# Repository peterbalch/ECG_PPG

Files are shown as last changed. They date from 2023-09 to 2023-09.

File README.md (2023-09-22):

# ECG_PPG
3D-print files for PPG
3D-print files for ECG-PPG finger sensor clip in DesignSpark Mechanical format.
Also STL files.

The complete Instructable is at:

https://www.instructables.com/ECG-With-PPG-Using-Arduino/

I've included preliminary copies of the Instructable (as PDF) and the Arduino files here but they are not going to be updated. For the latest versions, see the Instructable.

If you have queries, please ask them on the Instructable web page. I will not monitor Github for comments.

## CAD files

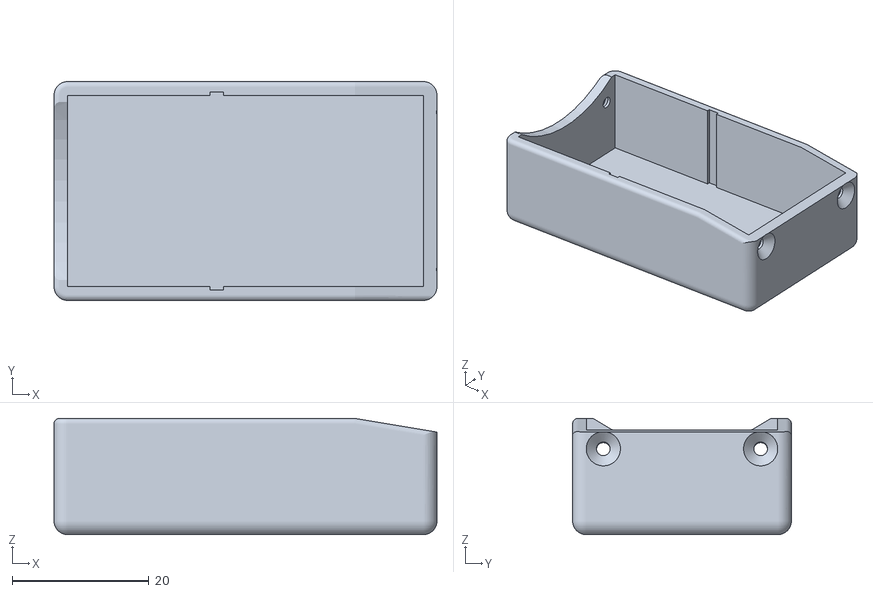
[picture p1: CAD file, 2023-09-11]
upper_box.stl
56.0 x 32.0 x 17.0

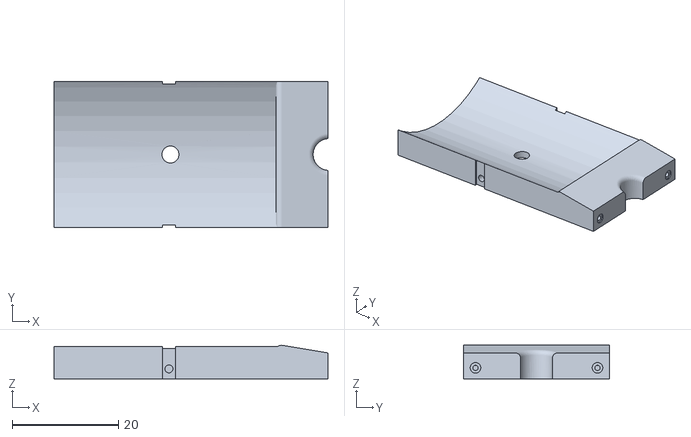
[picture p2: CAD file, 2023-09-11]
lower_slab.stl
51.7 x 27.6 x 6.32

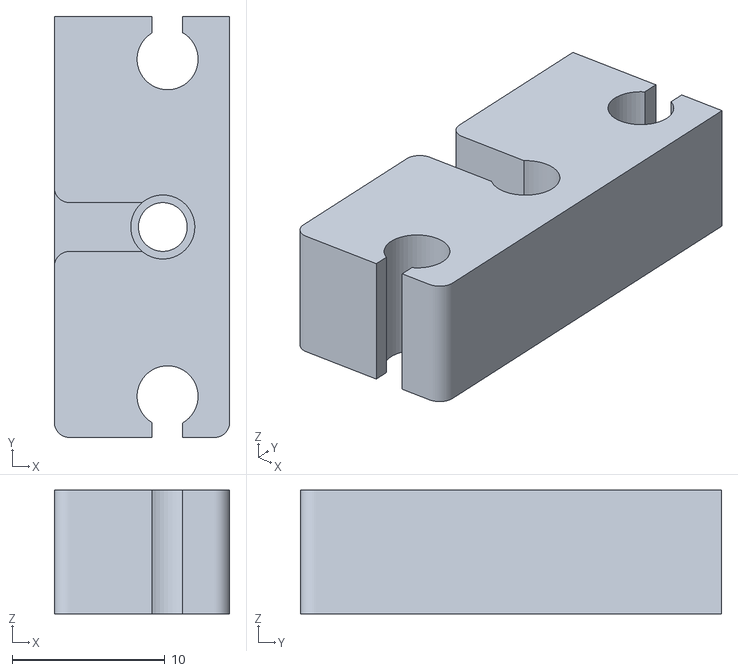
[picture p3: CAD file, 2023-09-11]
upper_led.stl
11.5 x 27.6 x 8.10

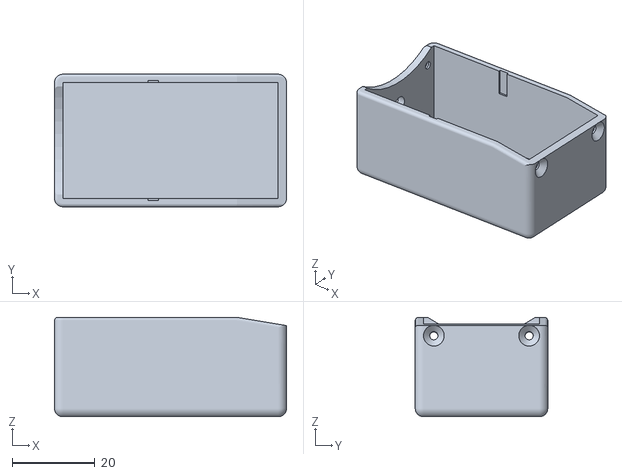
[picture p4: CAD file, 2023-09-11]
lower_box.stl
56.0 x 32.0 x 24.0

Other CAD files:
upper_slab.stl

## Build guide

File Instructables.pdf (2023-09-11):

### Introduction: ECG With PPG Using Arduino

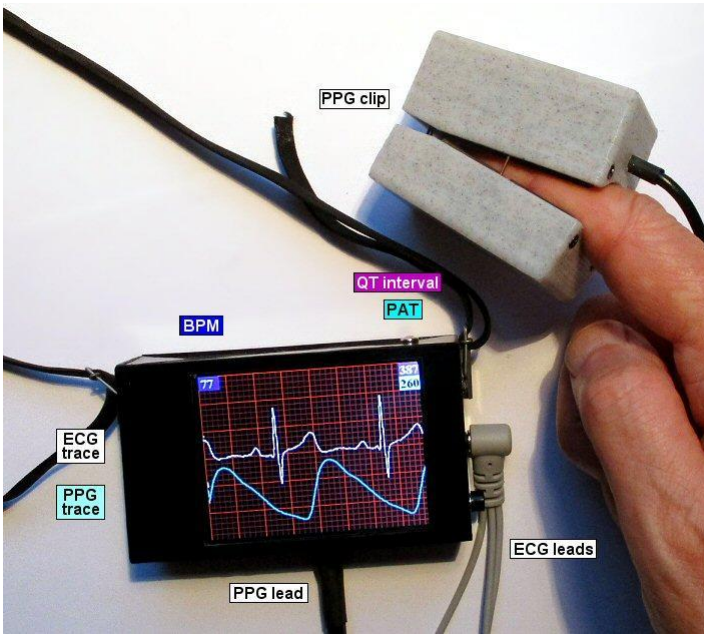
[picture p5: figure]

A plethysmogram is a graph of blood volume vs time and a photoplethysmogram (https://en.wikipedia.org/wiki/Photoplethysmogram) (PPG) uses light to measure blood volume, often with a finger probe.

You can buy a pulse oximeter very cheaply on eBay. It uses photoplethysmography to measure your heart-rate. By comparing the absorption of IR versus red light, it can also measure blood oxygen saturation. It's straightforward to build a PPG that measures red and IR absorption but calibrating it is a problem. The PPG described here only uses IR light.

This project is an add-on to my ECG project (https://www.instructables.com/ECG-Display-With-Arduino/) - I'm going to assume you've already built the ECG hardware. The additional hardware and software displays a photoplethysmogram next to the ECG trace. A probe clips on your finger and passes infra-red light through it. The amout of IR received is a measure of the blood volume in your finger.

There are two circuits you can use to collect the PPG data:

- build your own amplifier
- use an AD8232 module

Building your own amplifier is slightly cheaper and you probably already have all of the components. An AD8232 module is less work but you have to wait for it to be delivered.

I've included a design for a 3D printed PPG clip or you can use a piece of PVC plumbing pipe.

The new software includes code to calculate the QT-interval of the ECG signal. If you have built my ECG project, you can upgrade that project to display the QT-interval. (See the "Analysis" Step below.) You don't need to build PPG hardware.

This is not a medical device, it's something you're building for fun. See the full disclaimer in Step 2 of my ECG project. (https://www.instructables.com/ECG-Display-With-Arduino/)

### Step 1: What Is Photoplethysmography?

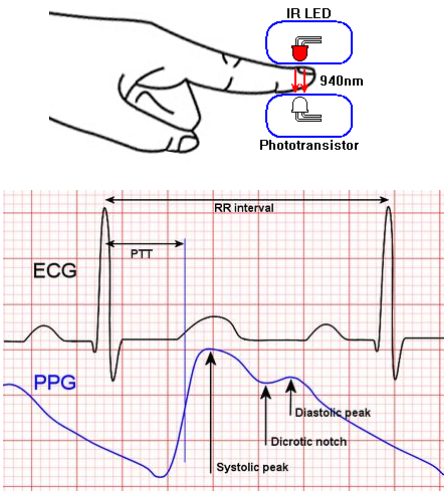
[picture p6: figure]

A PPG wave has a fast rise and a slow decline. During the decline there is a second peak. The first peak is the "systolic peak" and the second peak is the "diastolic peak". The dip between the two peaks is the "dicrotic notch".

The systolic peak is due to the pulse of blood arriving from the heart after systole (when the ventricles contract). The diastolic peak is due to reflection of that pulse from more peripheral parts of the blood system.

The size of the diastolic peak varies with where on the body you measure the PPG. It is quite large on the forehead and almost disappears at the toes.

The size of the diastolic peak also varies with age. It is quite large for young people and becomes smaller with age. The dicrotic notch is also large for young people and becomes smaller with age.

The heart rate can easily be measured using PPG and hence PPG can help detect arrythmia, tachycardia, atrial fibrillation, etc. But they can also be detected using the ECG trace.

The overall height of the PPG wave can be used to detect your breathing rate. There is decreased pulse amplitude and heart rate increases during inspiration. These effects are quite small and there are easier ways to detect respiration.

The time between the R wave of the ECG (the bigest peak) and the steepest part of the rise towards the systolic peak of the PPG is called the Pulse Arrival Time. (There are other slightly different definitions.)

The Pulse Transit Time is the time taken for the pulse to travel from, say, the shoulder to the finger or the face to the toe.

- PAT (pulse arrival time) - the time for the pulse to get from the heart to the

PPG probe

- PTT (pulse transit time) - the time for the pulse to get from, e.g., the

shoulder to the finger

But some people refer to both as Pulse Transit Time.

I'm going to refer to the time from the R-wave to the finger as PAT.

A typical PAT is in the range 200mS to 300mS.

Both Pulse Arrival Time (PAT) and Pulse Transit Time (PTT) can be used to estimate , arterial stiffness, artherosclerosis, arteriosclerosis, etc. But there is a lot of natural variation between individuals. The relationship between PAT and blood pressure has to be calibrated for each person. PAT may be useful to signal a sudden change in blood pressure, for instance, during a clinical procedure; it could signal the change faster than a cuff would.

The overall height of of the PPG is proportional to the pulse pressure. Pulse pressure is the difference between the systolic and diastolic pressure in the arteries. Higher pulse pressure may increase the risk heart attack or stroke. It may indicate atherosclerosis and stiffer arteries. Of course, the amplitude also depends on how far you've poked your finger into the PPG clip.

PPG is an active area of research. The bottom line is that it may be useful for diagnosis or it may not. The normal differences between individuals may be larger than the differences due to various health conditions. So it seems that you can use PPG to monitor changes in an andividual but not compare that individual to the general population.

There are many good reviews and discussions online, for instance here, (https://peterhcharlton.github.io/publication/ppg_sig_proc_chapter/) here (https://www.frontiersin.org/articles/10.3389/fphys.2021.808451/full) and here. (https://www.nature.com/articles/s41746-019-0136-7)

### Step 2: AD8232 Circuit

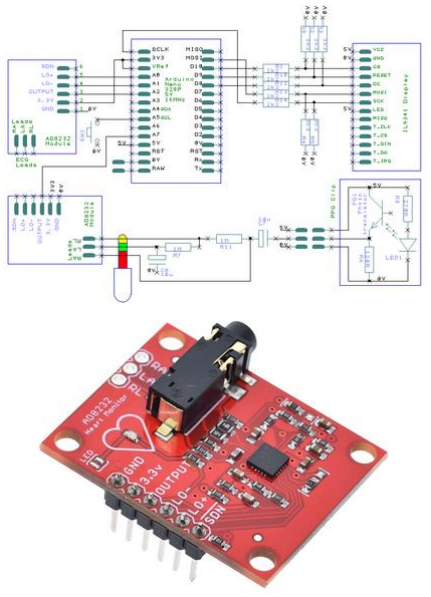
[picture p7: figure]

Skip to the next Step if you are building your own amplifier.

The AD8232 chip contains a high quality, low noise instrumentation amplifier and signal conditioning to remove noise. It is intended primarily for recording ECG but it works very well to record a PPG signal.

Buy a module like the one in the photo. Search eBay for "AD8232 module" or "ecg module". You don't need one with leads and electrode pads. You should already have a similar module measuring ECG.

R8 and LED1 produce infra-red light which passes through your finger to PD1. The current through PD1 produces a voltage across R1. That voltage is AC-coupled to the RA and LA inputs of the AD8232 module. The RA and LA inputs of the AD8232 module are connected to the RL (driven ground) output of the AD8232 through 1M resistors. That keeps the voltages at RL and RA in the correct range.

You can connect the PPG circuit to the AD8232 module using a 3.5mm jack plug or just solder the wires into the holes in the AD8232 PCB.

I suggest that you build the circuit on stripboard - it has very few components.

The value of R6 determines how large is the PPG signal. Try values between 100R and 470R.

The module produces mains hum when you connect the circuit to a computer with a USB lead. The hum goes away when the unit is disconnected.

### Step 3: Home-made Amplifier Circuit

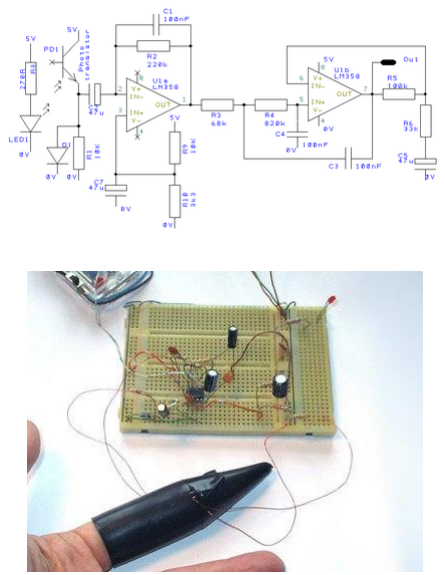
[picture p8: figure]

Skip to the next Step if you are using an AD8232 module.

The circuit consists of an IR LED emitter, an IR phototransistor receiver and an amplifier/filter based on an LM358 op-amp.

The current through the phototransistor produces a voltage across R1. That voltage is AC-coupled to the input of U1a (with a cutoff frequency of 3Hz). U1a has a V/V gain of 22x. C1 gives a slow roll-off above 7Hz. The circuit around U1b makes a low-pass Butterworth filter of around 10Hz with a V/V gain of 3x. Analog publish a good filter design tool here. (https://tools.analog.com/en/filterwizard/)

R1 is AC-coupled to U1a because if it is DC-coupled then changes in the overall light level shift the voltage across R1 and might drive the op-amp output to the power rail. If there is no finger in the clip then R1 goes to 5V

(or whatever the power level is). When you insert a finger, it takes up to 10sec for C1 to discharge to a reasonable input level for U1a. D1 stops R1 going above Vf of D1 (about 0.6V for a silicon diode). The circuit will work fine without D1 but it takes ages to get going. D1 can be any smallsignal silicon diode.

The IR LED is driven through a 270 ohm resistor giving a current of 15mA to 18mA. IR LEDs can often take up to 50mA but I wasn't wanting to drain the battery too quickly.

The output signal from U1b is around 1V high.

The IR emitter and receiver should have a wavelength in the range 900nm
- 940nm. Those wavelngths will pass through skin, muscle blood, etc. But they will be partially blocked if you have dark skin - that's because the job of melanin is to block light.

Choose an IR transmitter that matches the wavelength of the receiver. I chose

- IR LED = L-34F3C
- IR phototransistor = L-3DP3C

which peak at 940nm. Many other LEDs and phototransistors would work equally well - I happened to have lots of those ones. Search eBay or your favourite supplier for "IR LED" and "IR phototransistor" and choose ones that are 3mm dia. Make sure the wavelength is in the range 900nm -940nm.

The circuit is powered by a lithium cell (up to 4.2V) or from 4xAA cells (see Step 12 of my ECG project). So the "5V" in the schematic just means either 4V from the lithium cell or 5V from the Arduino.

If you were building this as a medical device, you'd use different filtering. You'd worry about the phase-shifts introduced by the filters - Chebyshev and Butterworth filters have different phase-shift. And you'd use a better quality op-amp!

### Step 4: Building the Circuit

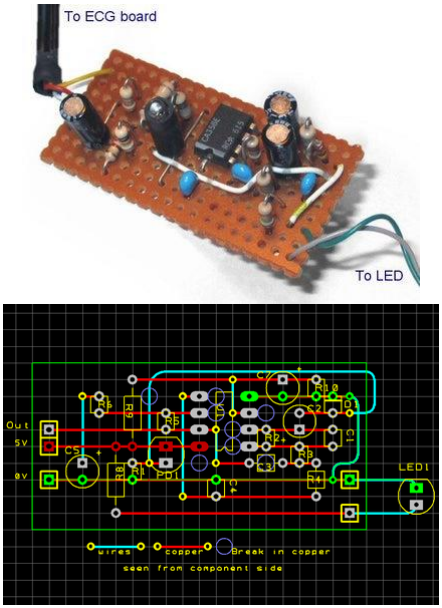
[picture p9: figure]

If you you have built your own amplifier:

I built the circuit on stripboard. It's a simple circuit and I'm far too impatient to wait for a commercial PCB. To keep the area small, I mounted most of the resistors vertically. The board is 1"x2" and is 15mm high. You can see the layout I used. If you prefer to use a "real" PCB then you can use SM parts to keep the height down.

The phototransistor is mounted in the centre of the board. The board is held in place in the clip with foam rubber arranged so the phototransistor pokes through a hole in the clip.

The LED is mounted in the other half of the clip on the end of wires. It is glued in place - I used UHU which is strong enough to work but can be pulled apart if you need to.

If you are using an AD8232 module:

The phototransistor, LED, R6 and R8 can be assembled inside the PPG clip. The R7, R11, C7 and C8 can be soldered onto a small piece of stripboard inside the case of your ECG.

### Step 5: Probe Clip

3 More Images

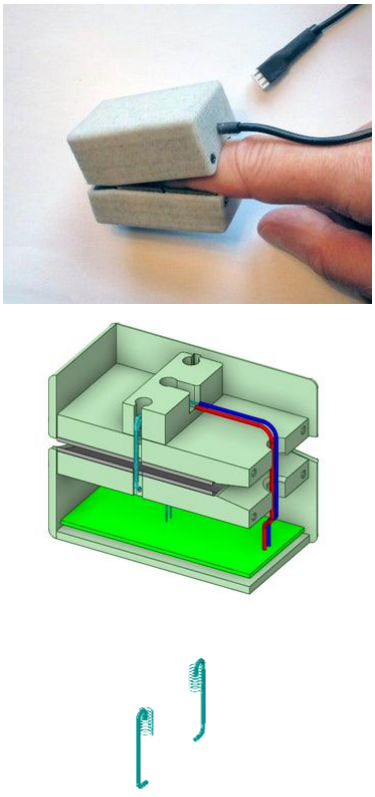
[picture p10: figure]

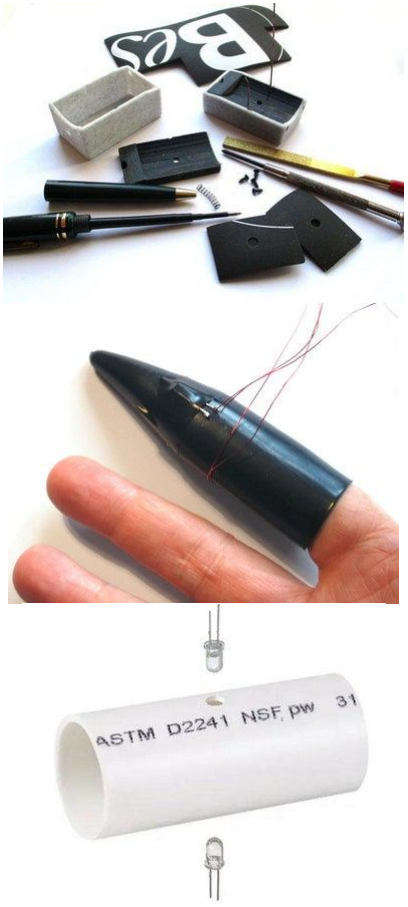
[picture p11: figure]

I used a 3D-printer to make the probe clip. The STL files are attached below.

As is usual with 3D-printing, you'll need to sand, file and drill the pieces so they fit. You'll need a 3.5mm (and maybe a 4mm) drill for the LED holes and maybe a 1.5mm drill for the screw-holes (depending on what screws you use).

The CAD model was designed using Designspark Mechanical. A free version can be downloaded (https://www.rs-online.com/designspark/mechanical-download-and-installation) from RS components. My Designspark source files are available here. (https://github.com/peterbalch/ECG_PPG)

I lined the clip with 1mm thick soft rubber from an old mouse-mat. It makes a better light-proof seal to your finger and is more comfortable. Bicycle inner-tube would also work.

The two halves of the clip are held together by bent wire and springs. I used a spring from a ballpoint pen that I cut in half. The wire is 0.5mm steel; a fine paperclip might work.

The clip is screwed together with 2x6mm self-tapping screws. Search eBay for "M2 countersunk self tapping screw". I find they're a useful size for assembling small 3D-printed items.

During development, I taped the LED and phototransistor into the walls of a black plastic tube. If you don't want to 3D-print a clip, you could make a more permanent version of that setup perhaps by using PVC plumbing tubing. "1/2 inch" pipe has an outside diameter of 21.4mm and an inside diameter of 18.0mm which should be OK unless you have particularly large fingers.

If you are using an AD8232 module: You don't need a big box on the PPG clip to house the amplifier - it's inside the case of the ECG. So print two copies of the smaller, "upper" box.

Attachments

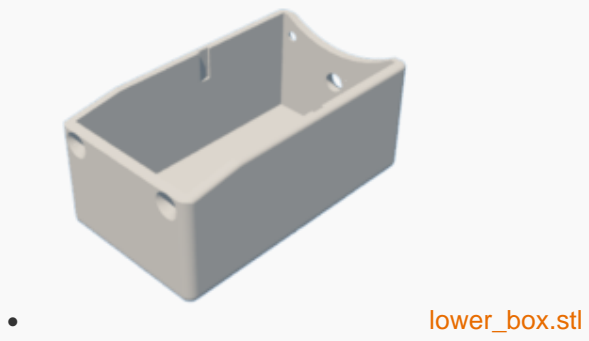
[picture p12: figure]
• lower_box.stl

Download (https://content.instructables.com/FBT/Z6LY/LMC1DFX6/FBTZ6LYLMC1DFX6.stl) | View in 3D

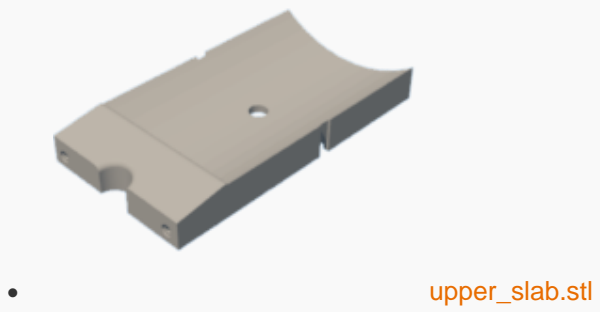
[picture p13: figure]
• upper_slab.stl

Download (https://content.instructables.com/FD6/OGLG/LMC1DFX5/FD6OGLGLMC1DFX5.stl) | View in 3D

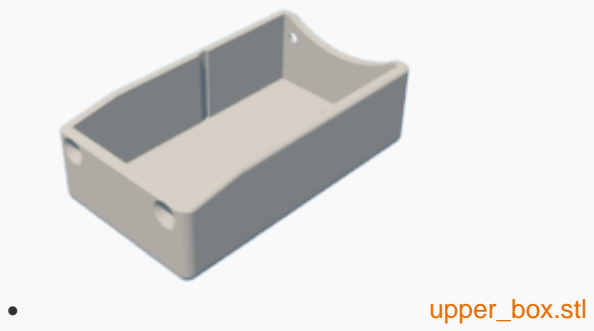
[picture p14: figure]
• upper_box.stl

Download (https://content.instructables.com/F60/IVPP/LMC1DFX8/F60IVPPLMC1DFX8.stl) | View in 3D

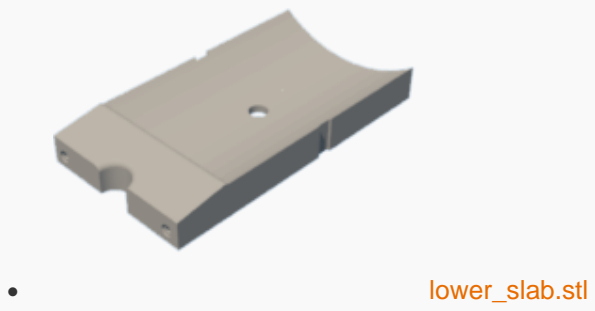
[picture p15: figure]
• lower_slab.stl

Download (https://content.instructables.com/FNC/DNY2/LMC1DFX7/FNCDNY2LMC1DFX7.stl) | View in 3D

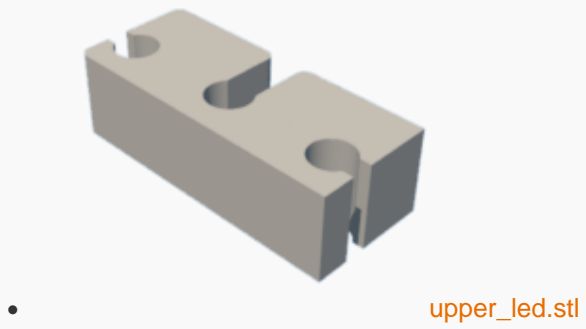
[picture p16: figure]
• upper_led.stl

Download (https://content.instructables.com/FQW/SJZ5/LMC1DFX9/FQWSJZ5LMC1DFX9.stl) | View in 3D

### Step 6: ECG Unit Hardware

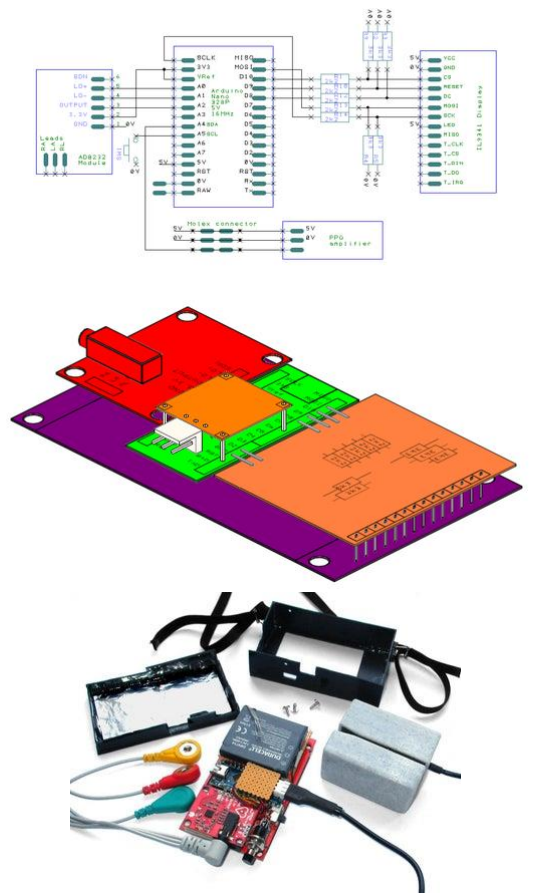
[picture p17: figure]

This plethysmogram is an add-on to my ECG project. The output from the PPG is connected to the A4 analogue input of the Arduino.

I decided to use a 3-pin 0.1" Molex connector. A stereo jack would look nicer but the AD8232 module of the ECG already uses a 3.5mm jack. It's important that the two connectors cannot be confused: you don't want to connect the 5V supply to the ECG electrodes attached to your body. A 2.5mm stereo jack would be better than a 0.1" Molex but I didn't have a 2.5mm plug/socket to hand.

If you you have built your own amplifier: The three wires connect to 0V, 5V and A4 of the Arduino Nano.

If you are using an AD8232 module: The phototransistor, LED, R6 and R8 can be assembled inside the PPG clip. The R7, R11, C7 and C8 can be soldered onto a small piece of strip-board inside the case of your ECG.

### Step 7: ECG Unit Software

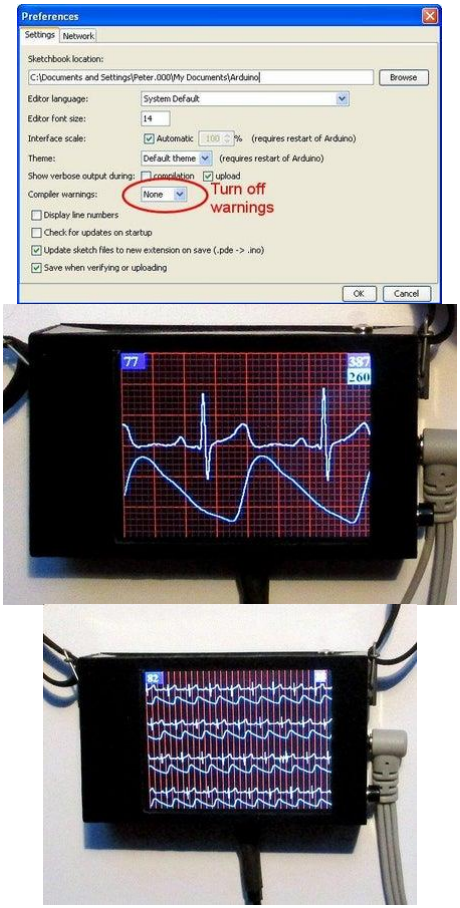
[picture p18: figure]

The PPG signal is shown when the ECG software is in the "Large display" or "Small display" mode. The PPG trace is drawn in cyan.

Download the files below. Copy the following files to a folder called ArduECGPPG:

- ArduECGPPG.ino
- SimpleILI9341.h
- SimpleILI9341.cpp

Turn off warnings. My code produces a lot of warnings which I find excessive and unhelpful. In the Arduino IDE (ver 1.8 or higher) select the File|Preferences menu item to open the Preferences dialog. Set Compiler Warnings to "None". Close the dialog.

To enable the PPG trace, ensure that bHasPPG is defined near the start of the sketch.

#define bHasPPG

If you comment it out then none of the PPG code will be executed.

Compile the files and upload them to the Nano.

If you you have built your own amplifier:

In ArduECGPPG.ino, A4 (the PPG signal) is defined as

pinMode(A4,INPUT_PULLUP)

So that if the PPG clip is disconnected then the input is pulled up to 5V. The sketch recognises that the the PPG signal is high and doesn't display it.

If you are using an AD8232 module:

With the AD8232 module, that "pullup" trick doesn't work - the AD8232 always produces an output in the right range. However, when the PPG clip is disconnected from the AD8232 module, the module produces a lot of noise. So as an additional test, the sketch looks at the total "energy" (the total changes across the sweep). If the "energy" is greater than a threshold then the next sweep of the screen is not displayed.

Attachments

- ArdECGPPG.ino

Download (https://content.instructables.com/F5Y/FW8Y/LMC1DK34/F5YFW8YLMC1DK34.ino)

- SimpleILI9341.cpp

Download (https://content.instructables.com/FPA/8KQ7/LMC1DK35/FPA8KQ7LMC1DK35.cpp)

- SimpleILI9341.h

Download (https://content.instructables.com/F6H/KKB0/LMC1DK36/F6HKKB0LMC1DK36.h)

### Step 8: Analysis

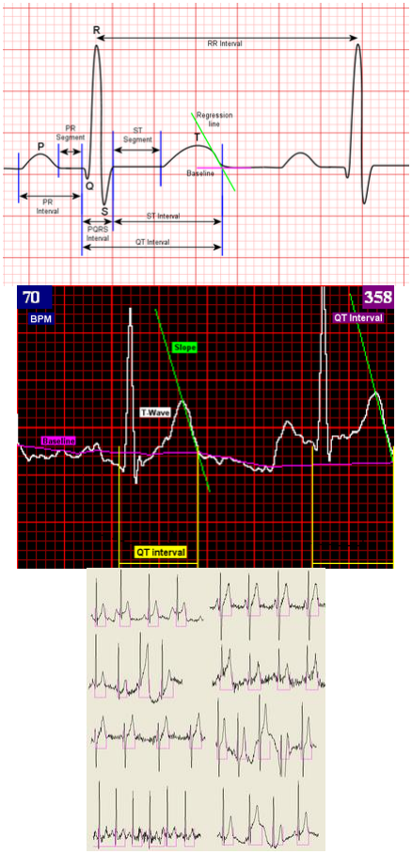
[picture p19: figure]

The interval between the ECG and the PAT is displayed.

PAT is measured from the peak of the ECG R-wave to somewhere in the systolic peak. Some researchers measure to the top of the systolic peak and some measure to the biggest upward slope of the systolic peak (which is what this sketch does).

The sketch has a new feature: it can estimate the QT interval. To enable QT estimation ensure that bHasQT is defined near the start of the sketch.

#define bHasQT

QT interval is a useful measurement in predicting ventricular arrhythmias. "Long QT syndrome" can be congenital or due to various medications.

It is hard to automate the calculation and many doctors don't trust automated systems. There are lots of different attempts at algorithms which implies to me that the problem has not been "solved". The result you get can depend on where you've placed the leads.

The QT interval is defined to be the time from the start of the Q-wave to the end of the T-wave. (https://en.wikipedia.org/wiki/T_wave) The start of the Q-wave is the time at which the ECG signal starts to dip just before the large R spike. The end of the T-wave is where a line drawn through the falling part of the T-wave meets the baseline. In textbooks, it looks easy.

In the real world it's much harder. There is noise in the signal. Where is the "baseline"? What is the slope of the T-wave? Where do you measure it?

The rest of this Step describes my solution. You can skip it unless you're interested in the maths.

The start of the Q-wave is easy. It's the sample after the last time the differential of the signal was positive before the R spike. You have to smooth the signal to remove the worst noise. I say that the Q-wave is easy because the Q-wave is so quick that any mistake you make will only affect the estimated QT-interval by a few milliSeconds.

The T-wave is harder because it's slower and more vague. The algorithm I've developed for finding the end of the T-wave is as follows.

The ECG signal is differentiated and smoothed. The peak of the R-wave corresponds with the biggest value of the differentiated ECG signal.

The peak of the T-wave is located. It is the highest value of the ECG signal that is between 200mS and 500mS after the R-wave.

Once the peak of the T-wave is found, the program calculates the regression line of the signal from the peak to 100mS after the peak. The program starts collecting:

- the sum of a
- the sum of T
- the sum of T*a
- the sum of T*T

(where 'T' is the time since the R-peak and 'a' is the ECG signal)

The summing stops 100mS after the R-peak and the line is calculated. However the values are weighted so that values half through the 100mS interval are worth more.

The values that have been summed allow us to calculate the regression line. (https://en.wikipedia.org/wiki/Linear_regression)

You will have been taught the formula for regression in any statistics course:

a = (Σxy - Σx*Σy/n)/(Σx²-Σx*Σx/n);
b = (Σy-a*Σx)/n;
(where y = ax + b}

The end of the T-wave is where the line crosses the "baseline" but where is the baseline?

The ECG signal is exponentially smoothed. (https://en.wikipedia.org/wiki/Exponential_smoothing) When each sample arrives, it is smoothed using

smoothed_sample = smoothed_sample*alpha + sample*(1-alpha); Alpha ought to be calulated as

alpha = exp(-1/Tau);
but it can be approximated more cheaply as

alpha = 1 - 1/Tau;
The bigger Tau (the time-constant) the more the signal is smoothed; i.e. the more slowly the smoothed signal changes.

The estimated baseline is an exponentially smoothed copy of the signal. The time-constant of the exponential is longer when the signal is further from the current estimated baseline:

- "sample" is latest sample
- diff is (first derivative of sample)²
- ds is diff smoothed with time_const=20mS
- Tau = 2*(ds+sqr(sample-baseline)+1)

The baseline is "sample" (the latest sample) smoothed using a time-constant of Tau. So the baseline changes slowly due to big sudden changes (like the R-wave and T-wave) but stays close to (what a human thinks is) the true baseline.

The "first derivative of sample" is, in fact, sample[i]-sample[i-n]. Where n is chosen to be around 20mS before. (The larger the value of "n", the more the differential is smoothed.)

I admit, a lot of the algorithm is rather arbitrary but it works at least as well as other algorithms you can find in scientific papers. The images above show the results when applied to a database (https://physionet.org/content/ecgiddb/1.0.0/) of typical "real world" recordings that contain all sorts of errors.

The normal QT interval is in the range:

- Men 390 - 450ms
- Women 390 - 460ms

but it depends on the heart-rate. The QT interval is therefore adjusted to compensate for heart-rate to give QTc.

Several compensation formulae are used:

- Bazett formula: QTc = QT/sqrt(RR/1000)
- Fridericia formula: QTc = QT/((RR/1000)^(1/3))
- Framingham formula: QTc = QT + 0.154 * (1 - RR)
- Hodges formula: QTc = QT + 0.154*(1000-RR)

(QT and RR are in mS.)

Graphs of those formulae are shown above: a QT interval of 400mS is "compensated" for various heart-rates.

I have chosen the Fridericia formula which is widely used. In fact, I've recalculated the Fridericia formula as a quadratic equation so as not to have to calculate a cube root (which is very slow on a Nano). I'll call it "Peter's formula":

- Peter's formula: QTc = QT * ((0.00728 - 0.0000164*BPM)*BPM + 0.622)

It gives the same answer as the Fridericia formula to within about 1mS over the normal range QT interval and heart-rate (BPM).

The QTc value that the program displays is the calculated QTc filtered through an order-5 median filter and a low-pass filter. A median filter is useful when noise give rise to a couple of really weird values. The low-pass filter stops the displayed values changing too quickly.

### Step 9: The Future

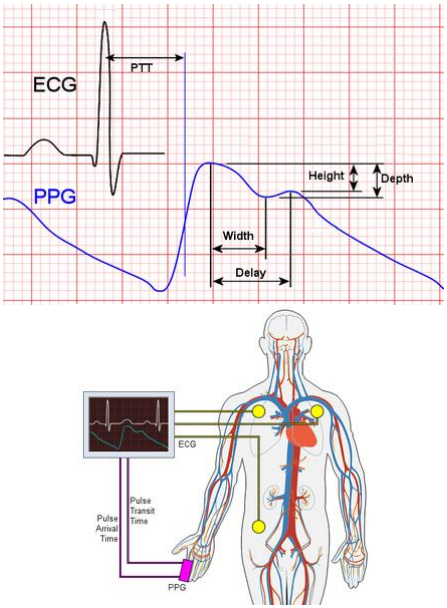
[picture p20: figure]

How can this project be taken forward?

You could save power by only turning on LED when measuring - but then the amplifier must respond quickly and filtering must be done in s/w. You could measure the light level twice with the LED off then on and use the difference to compensate for ambient light levels.

You could automate further analysis of the PPG signal. Researchers have tried to automate the measurement of various aspects of the PPG signal:

- the pulse arrival time (PAT)
- the rise time of the systolic pulse

- the fall time of the diastolic pulse
- the relative heights of the systolic and diastolic peaks
- the time from systolic peak to diastolic peak
- the amplitude of the systolic peak
- the depth of the dicrotic notch
- the areas of different parts of the curve

Researchers attempt to correlate different measurements with blood pressure, stroke volume, arterial stiffness, atherosclerosis, pain level, breathing rate, etc. They look at the first, second and third derivative of the PPG and even use Fourier transforms and wavelet analysis. By comparing PAT for proximal and distal PPGs, the state of different arteries can be estimated.

The problem is that differences between individuals are large. It can depend on skin type, ambient light, limb length, body temperature, etc. You need to calibrate each individual so it is only useful statistically with large populations or to asses the ongoing response of an individual to treatment.

You could add a second PPG probe and measure both pulse arrival time and pulse transit time. This group (https://ieeexplore.ieee.org/abstract/document/9646921) use a clip as long as the finger with a PPG sensor at each end to measure pulse wave velocity. They claim that it's 90% accurate for systolic blood pressure and 63% accurate for diastolic blood pressure.

The current sketch measures the heart-rate and draws the Poincare display by looking at the ECG. You could dispense with the ECG altogether and display only the PPG and a Poincare display.

It would be nice to save a whole day's worth of data. That's about 68Mbytes of data (assuming one-byte values). The write time of an SD card is very variable so I would probably use two Arduinos: one to collect the samples and one to buffer them and write to the SD card.

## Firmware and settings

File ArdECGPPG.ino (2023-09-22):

//-----------------------------------------------------------------------------
// Copyright 2023 Peter Balch
//   displays an ECG and PPG
//   computes QT interval
//   computes PAT
//-----------------------------------------------------------------------------

#include <Arduino.h>
#include <SPI.h>
#include "SimpleILI9341.h"

//-----------------------------------------------------------------------------
// Defines
//-----------------------------------------------------------------------------

#define bHasPPG
#define bHasPAT
#define bHasQT
#define bHasChartMode

#ifdef bHasPAT
#define bHasPPG
#endif

//#define bDebug
//#define bWindows
//#define bFakeECGoutput
//#define bFakeInput

// get register bit - faster: doesn't turn it into 0/1
#ifndef getBit
#define getBit(sfr, bit) (_SFR_BYTE(sfr) & _BV(bit))
#endif
#define sqr(x) ((x)*(x))

//-----------------------------------------------------------------------------
// Global Constants and Typedefs
//-----------------------------------------------------------------------------

const int TFT_WIDTH = 320;
const int TFT_HEIGHT = 240;

// pins
const int ECG_IN = A2;
#ifdef bHasPPG
const int PPG_IN = A4;
int16_t ppgmin = 1024;
static uint32_t ppgEnergy = 0;
#endif

#ifdef bFakeECGoutput
const int FAKE_OUT = 3;
#endif

const int BUTTON_IN = A5;
const int LO_P_IN = A0;
const int LO_N_IN = A1;

// Display pins
const int TFT_CS    = 10;
const int TFT_CD    = 8;
const int TFT_RST   = 9;

const int sps = 200; // Samples per Sec
const int SamplePeriod = 1000 / sps; // mSec
const int PoincareScale = 10;
const int PoincareLeft = 40;
const int PoincareBottom = TFT_HEIGHT - 12;
const int nDiff = sps / 65; /* differentiate = aa[i]-aa[i-nDiff]*/

//-----------------------------------------------------------------------------
// Global Variables
//-----------------------------------------------------------------------------

uint16_t DisplayRepeat = TFT_WIDTH; // helps keep the R peak centred
uint8_t ignoreBeats = 0; // blank the screen after an error
int16_t lastNegDiff1, lastNegDiff2; // how long ago was the last time the differential was negative
uint16_t CurBPM = 60;
#ifdef bHasPPG
  uint8_t PPGreceived = 0; // count how many PPG signals (value < 1000) have been received to check that the PPG is plugged in
  const uint8_t PPGreceivedMin = 100; // must have received >= 100 valid values
#endif
#ifdef bHasQT
  uint16_t CurQT = 360;
#endif
#ifdef bHasPAT
  float CurPAT = 0;
#endif

enum TMode { mdLargeECG, mdSmallECG,  mdPoincare, mdBattery } mode = mdLargeECG;

bool SendingSerial = false;

//---------------------------------------------------------------------------

#ifdef bFakeInput
#include "FakeInput.h"
#endif

//---------------------------------------------------------------------------
// TimeConst
//   calc Alpha for a time constant of a decay
//    n: number of samples for exponential smoothing
//    returns exp(-1 / n);
//---------------------------------------------------------------------------
float TimeConst(float n) {
  return exp(-1 / n);
}

//---------------------------------------------------------------------------
// MedianOfThree
//    c,d,e: three values
//    returns median value
//---------------------------------------------------------------------------
int16_t MedianOfThree(int16_t c, int16_t d, int16_t e) {
  int16_t tmp;
  if (d < c) {    tmp = c;    c = d;    d = tmp;  };
  if (e < c) {    e = c;  };
  if (d < e) return d; else return e;
}

//---------------------------------------------------------------------------
// MedianOfFive
//    a,b,c,d,e: five values
//    returns median value
//---------------------------------------------------------------------------
int16_t MedianOfFive(int16_t a, int16_t b, int16_t c, int16_t d, int16_t e) {
  int16_t tmp;
  if (b < a) {    tmp = a;    a = b;    b = tmp;  }
  if (d < c) {    tmp = c;    c = d;    d = tmp;  }
  if (c < a) {    tmp = b;    b = d;    d = tmp;    c = a;  }
  if (b < e) {    tmp = e;    e = b;    b = tmp;  }
  if (e < c) {    tmp = b;    d = tmp;  e = c;    }
  if (d < e) return d; else return e;
}

//-----------------------------------------------------------------------------
// DrawGridSmall
//   draw empty grid for small display
//-----------------------------------------------------------------------------
void DrawGridSmall(void)
{
  int16_t  i;
  ClearDisplay(TFT_BLACK);

  #ifdef bHasChartMode
    for (i=0; i < TFT_WIDTH; i++)
      if (i*4*5 % sps == 0)
        DrawVLine(i, 0, TFT_HEIGHT/4, TFT_RED);
    for (i=TFT_HEIGHT/4; i < TFT_HEIGHT; i+=TFT_HEIGHT/16)
      if (i % (TFT_HEIGHT/4) == 0)
        DrawHLine(0, i, TFT_WIDTH, TFT_DARKGRAY); else
        DrawHLine(0, i, TFT_WIDTH, TFT_MAROON);
  #else
    for (i = 0; i < TFT_WIDTH; i++)
      if (i*4*5 % sps == 0)
        DrawVLine(i, 0, TFT_HEIGHT, TFT_RED);
  #endif
}

//-----------------------------------------------------------------------------
// DrawPoincareLine
//   draw a Line on the Poincare display
//    x1,y1: start point
//    x2,y2: end point
//    color: the color it is to be drawn
//-----------------------------------------------------------------------------
void DrawPoincareLine(int16_t x1, int16_t y1, int16_t x2, int16_t y2, uint16_t color)
{
  DrawLine(
    constrain(PoincareLeft + x1 / PoincareScale, 0, TFT_WIDTH - 1),
    constrain(PoincareBottom - y1 / PoincareScale, 0, TFT_HEIGHT - 1),
    constrain(PoincareLeft + x2 / PoincareScale, 0, TFT_WIDTH - 1),
    constrain(PoincareBottom - y2 / PoincareScale, 0, TFT_HEIGHT - 1),
    color);
}

//-----------------------------------------------------------------------------
// DrawPoincareFrame
//   draw a rectangle Poincare display 
//    x1,y1,x2,y2: the corners of the frame
//    color: the color it is to be drawn
//-----------------------------------------------------------------------------
void DrawPoincareFrame(int16_t x1, int16_t y1, int16_t x2, int16_t y2, uint16_t color)
{
  DrawPoincareLine(x1, y1, x2, y1, color);
  DrawPoincareLine(x2, y1, x2, y2, color);
  DrawPoincareLine(x2, y2, x1, y2, color);
  DrawPoincareLine(x1, y2, x1, y1, color);
}

//-----------------------------------------------------------------------------
// DrawGridPoincare
//   draw Poincare display background
//-----------------------------------------------------------------------------
void DrawGridPoincare(void)
{
#define TFT_DARKDARKGRAY    RGB(64,64,64)
  const uint8_t f[4] = { 30, 60, 100, 160 };
  int16_t i, b;

  ClearDisplay(TFT_BLACK);

  for (i = 0; i < sizeof(f); i++) {
    b = 60000 / f[i] / PoincareScale;
    DrawVLine(PoincareLeft + b, 0, PoincareBottom, TFT_DARKDARKGRAY);
    DrawHLine(PoincareLeft, PoincareBottom - b, TFT_WIDTH, TFT_DARKDARKGRAY);
    ILI9341SetCursor(PoincareLeft + b - 8, TFT_HEIGHT);
    DrawInt(f[i], MediumFont, TFT_WHITE);
    ILI9341SetCursor(PoincareLeft - 20, PoincareBottom - b + 4);
    DrawInt(f[i], MediumFont, TFT_WHITE);
  }
  DrawLine(PoincareLeft, PoincareBottom, PoincareLeft + PoincareBottom, 0, TFT_DARKDARKGRAY);

  DrawPoincareLine(500, 500, 1115, 916, TFT_DARKGREEN); // normal
  DrawPoincareLine(1115, 916, 1115, 1115, TFT_DARKGREEN);
  DrawPoincareLine(1115, 1115, 916, 1115, TFT_DARKGREEN);
  DrawPoincareLine(916, 1115, 500, 500, TFT_DARKGREEN);
  DrawPoincareFrame(500, 1200, 700, 2500, TFT_MAROON); // N-V-N
  DrawPoincareFrame(1200, 500, 2500, 700, TFT_MAROON);
  DrawPoincareFrame(500, 500, 700, 1200, RGB(48, 48, 0)); // premature ventricular
  DrawPoincareFrame(500, 500, 1200, 700, RGB(48, 48, 0));
  DrawPoincareLine(320, 320, 320, 650, RGB(0, 0, 64)); // atrial fibrilation
  DrawPoincareLine(320, 650, 800, 1700, RGB(0, 0, 64));
  DrawPoincareLine(800, 1700, 1700, 1700, RGB(0, 0, 64));
  DrawPoincareLine(1700, 1700, 1700, 800, RGB(0, 0, 64));
  DrawPoincareLine(650, 320, 1700, 800, RGB(0, 0, 64));
  DrawPoincareLine(650, 320, 320, 320, RGB(0, 0, 64));
  DrawPoincareFrame(1700, 900, 2500, 1400, RGB(0, 32, 32)); // missed beat
  DrawPoincareFrame(900, 1700, 1400, 2500, RGB(0, 32, 32));

  DrawVLine(PoincareLeft, 0, PoincareBottom, TFT_WHITE);
  DrawHLine(PoincareLeft, PoincareBottom, TFT_WIDTH, TFT_WHITE);
}

//-----------------------------------------------------------------------------
// DrawGridVLine
//   for Large display, draw a part of the grid
//    x: column
//    y1,y2: ends of line
//-----------------------------------------------------------------------------
void DrawGridVLine(int16_t x, int16_t y1, int16_t y2)
{
  int16_t y;

  if (y1 > y2)
    DrawGridVLine(x, y2, y1); else
  {
    if (x * 5 % (1000 / SamplePeriod) == 0)
      DrawVLine(x, y1, y2 - y1 + 1, TFT_RED); else if (x * 25 % (1000 / SamplePeriod) == 0)
      DrawVLine(x, y1, y2 - y1 + 1, TFT_MAROON); else
    {
      DrawVLine(x, y1, y2 - y1 + 1, TFT_BLACK);
      for (y = y1; y <= y2; y++)
        if (y % 40 == 0)
            DrawPixel(x, y, TFT_RED); else if (y % 8 == 0)
          DrawPixel(x, y, TFT_MAROON);
    }
  }
}

//-----------------------------------------------------------------------------
// DrawPoincare
//   draw the current BPM in the Poincare display 
//    Poincare plot
//    init: initialise the points array?
//-----------------------------------------------------------------------------
void DrawPoincare(bool init)
{
  const int nPeriods = 400;
  static uint8_t Periods[nPeriods] = {0};
  static int16_t i = 0;
  int16_t prev,t;

  if (init) {
    memset(Periods, 0, sizeof(Periods));
    return;
  }

  t = 60000 / (CurBPM*PoincareScale);

  prev = Periods[i];
  i = (i + 1) % nPeriods;
  if (PoincareLeft + Periods[i] > 0)
    DrawPixel(PoincareLeft + Periods[i], PoincareBottom - (Periods[(i + 1) % nPeriods]), TFT_BLACK);
  Periods[i] = t;
  if (prev > 0)
    DrawPixel(PoincareLeft + prev, PoincareBottom - t, TFT_WHITE);
}

//-----------------------------------------------------------------------------
// DrawGridLarge
//   draw the background of the Large display 
//-----------------------------------------------------------------------------
void DrawGridLarge(void)
{
  int16_t i;
  ClearDisplay(TFT_BLACK);
  for (i = 0; i < TFT_HEIGHT; i++)
    if (i % 8 == 0)
      DrawHLine(0, i, TFT_WIDTH, TFT_MAROON);
  for (i = 0; i < TFT_WIDTH; i++)
    if (i * 25 % (1000 / SamplePeriod) == 0)
      DrawVLine(i, 0, TFT_HEIGHT, TFT_MAROON);

  for (i = 0; i < TFT_HEIGHT; i++)
    if (i % 40 == 0)
      DrawHLine(0, i, TFT_WIDTH, TFT_RED);
  for (i = 0; i < TFT_WIDTH; i++)
    if (i * 5 % (1000 / SamplePeriod) == 0)
      DrawVLine(i, 0, TFT_HEIGHT, TFT_RED);
}

//-----------------------------------------------------------------------------
// DrawGrid
//   draw the background of the current display 
//-----------------------------------------------------------------------------
void DrawGrid(void)
{
  switch (mode) {
    case mdLargeECG: DrawGridLarge(); break;
    case mdSmallECG: DrawGridSmall(); break;
    case mdPoincare: DrawGridPoincare(); break;
    case mdBattery: ClearDisplay(TFT_BLACK); break;
  }
  DisplayRepeat = TFT_WIDTH;
  DrawPoincare(true);
  ignoreBeats = 2;
}

//-----------------------------------------------------------------------------
// centrePeak
//   attempt to keep a peak in the first third of the screen
//    x: position of the peak being drawn
//-----------------------------------------------------------------------------
void centrePeak(uint16_t x)
{
  uint16_t period = (60000L/SamplePeriod) /CurBPM;
  int16_t b;
  static int16_t dr = 480;
  static int16_t dt = 0;

  b = period;
  while (b < TFT_WIDTH)
    b += period;
  if (b > dr+10)
    dr += 10; else
  if (b < dr-10)
    dr -= 10;
  if (b > dr)
    dr++; else
    dr--;
  dr = constrain(dr,TFT_WIDTH-1,2*TFT_WIDTH);
  DisplayRepeat = dr;
  if (x < 80)
    dt--; else
  if (x < 160)
    dt++;
  DisplayRepeat += dt;
  DisplayRepeat = constrain(DisplayRepeat,TFT_WIDTH-1,2*TFT_WIDTH);
}

//-----------------------------------------------------------------------------
// DrawBattVolts
//-----------------------------------------------------------------------------
void DrawBattVolts(void)
{
  const int xBatt = 50;
  const int yBatt = 100;
  static int maxBatt = 3300;
  static unsigned long nextTime = 0;
  int v = read3V3();
  const int w = 40;

  maxBatt = max(maxBatt, v);

  if (millis() > nextTime) {
    nextTime = millis() + 1000;
    ILI9341SetCursor(xBatt, yBatt + 15);
    DrawStringF(F("Battery "), LargeFont, TFT_WHITE);
    DrawBox(Cursorx, yBatt, 54, 20, TFT_BLACK);
    DrawInt(maxBatt, LargeFont, TFT_WHITE);
    maxBatt = 0;

    DrawBox(0, 0, 50, 20, TFT_NAVY);
    ILI9341SetCursor(4, 16);
    DrawStringF(F("BPM"), LargeFont, TFT_WHITE);
    #ifdef bHasQT
      DrawBox(TFT_WIDTH - w, 0, w, 20, TFT_PURPLE);
      ILI9341SetCursor(TFT_WIDTH - w + 2, 16);
      DrawStringF(F("QT"), LargeFont, TFT_WHITE);
    #endif
    #ifdef bHasPAT
      if (PPGreceived >= PPGreceivedMin) {
        #ifdef bHasQT
          const int y = 20;
        #else
          const int y = 0;
        #endif
        DrawBox(TFT_WIDTH - w, y, w, 20, TFT_CYAN);
        ILI9341SetCursor(TFT_WIDTH - w + 1, y + 16);
        DrawStringF(F("PAT"), LargeFont, TFT_BLACK);
      }  
    #endif
  }
}

//-----------------------------------------------------------------------------
// DrawChart
//   draw the current BPM and PAY in the vhart display 
//    init: initialise the display?
//-----------------------------------------------------------------------------
#ifdef bHasChartMode
void DrawChart(bool init)
{
  static int16_t x = -1;
  static uint8_t pyBPM = 0;
  static uint8_t pyPAT = 0;
  static uint8_t yofs = TFT_HEIGHT/4;
  int16_t y4, y;
  const int16_t  minBPM = 40;
  const int16_t  maxBPM = 150;
  const int16_t  minPAT = 150;
  const int16_t  maxPAT = 400;
  const int16_t  BPMmaxRed = 120; // BPM above this shown as red
  const int16_t  BPMmaxYellow = 100; // BPM above this shown as Yellow
  const int16_t  BPMminYellow = 50; // BPM below this shown as Yellow
  const int16_t  BPMminRed = 40; // BPM below this shown as red

  if (init) {
    x = -1;
    yofs = 0;
    return;
  }

  x++;
  x = x % TFT_WIDTH;

  if (x == 0) {
    yofs = (yofs+TFT_HEIGHT/4);
    if (yofs >= TFT_HEIGHT)
      yofs = TFT_HEIGHT/4;
  }

  DrawVLine(x, yofs+1, TFT_HEIGHT/4-1, TFT_BLACK);
  DrawVLine(x+1, yofs+1, TFT_HEIGHT/4-1, TFT_WHITE);
  DrawPixel(x, yofs, TFT_DARKGRAY);
  DrawPixel(x, yofs+TFT_HEIGHT/16, TFT_MAROON);
  DrawPixel(x, yofs+2*TFT_HEIGHT/16, TFT_MAROON);
  DrawPixel(x, yofs+3*TFT_HEIGHT/16, TFT_MAROON);

  // display BPM
  y4 = (CurBPM-minBPM)*TFT_HEIGHT/(4*(maxBPM-minBPM));
  y = constrain(TFT_HEIGHT/4-y4, 0,TFT_HEIGHT/4-1);
  if (x == 0)
    pyBPM = y;

  if ((CurBPM > BPMmaxRed) || (CurBPM < BPMminRed))
    DrawVLine(x, y+yofs, y4, TFT_MAROON); else
  if ((CurBPM > BPMmaxYellow) || (CurBPM < BPMminYellow))
    DrawVLine(x, y+yofs, y4, TFT_OLIVE); else
    DrawVLine(x, y+yofs, y4, TFT_DARKGREEN);

  if (y >= pyBPM)
    DrawVLine(x, pyBPM+yofs, y-pyBPM+1, TFT_WHITE); else
    DrawVLine(x, y+yofs, pyBPM-y+1, TFT_WHITE);

  pyBPM = y;

  #ifdef bHasPAT
    // display PAT
    y4 = (CurPAT-minPAT)*TFT_HEIGHT/(4*(maxPAT-minPAT));
    y = constrain(TFT_HEIGHT/4-y4, 0,TFT_HEIGHT/4-1);
    if (x == 0)
      pyPAT = y;

    if (y >= pyPAT)
      DrawVLine(x, pyPAT+yofs, y-pyPAT+1, TFT_CYAN); else
      DrawVLine(x, y+yofs, pyPAT-y+1, TFT_CYAN);

    pyPAT = y;
  #endif
}
#endif

//-----------------------------------------------------------------------------
// DrawCharCol
//   draws a single column of a character
//   used by DrawBoxIntCol
//     c: char to be drawn
//     Cursorx: position of char
//     Cursory: position of char
//     x: column to be drawn
//     Font: Font
//     color: foreground color
//-----------------------------------------------------------------------------
bool DrawCharCol(uint8_t c, int x, word Font, uint16_t color) {
  word n, j;
  byte ymax, desc;
  unsigned long b,d;

  ymax = pgm_read_byte_near(Font); // height of char
  Font++;
  desc = pgm_read_byte_near(Font); // size of descender
  Font++;

  j = pgm_read_byte_near(Font); // first char
  Font++;
  if (c < j) return false;

  while (c > j) {
    b = pgm_read_byte_near(Font); // number of columns in char
    if (b == 0)
      return false;
    if (ymax > 15)
      Font += b * 3 + 1;
    else if (ymax > 7)
      Font += b * 2 + 1;
    else
      Font += b + 1;
    c--;
  }

  // c now points at the start of the required character
  n = pgm_read_byte_near(Font); // number of columns in char
  Font++;

  if (Cursorx+n < x) {
    Cursorx += n;
  } else {
    while (n > 0) {
      if (Cursorx == x) {
        b = pgm_read_byte_near(Font);
        Font++;
        if (ymax > 7) {
          d = pgm_read_byte_near(Font);
          b |= d << 8;
          Font++;
        }
        if (ymax > 15) {
          d = pgm_read_byte_near(Font);
          b |= d << 16;
          Font++;
        }
        for (j = 0; j <= ymax; j++) {
          if (b & 1) 
            DrawPixel(Cursorx, Cursory + desc - j, color);
          b = b >> 1;
        }
        return true;
      } else {
        Font += ymax / 8 + 1;
      }

      Cursorx++;
      n--;
    }
  }
  Cursorx += letter_gap;
  return false;
}

//-----------------------------------------------------------------------------
// DrawBoxIntCol
//   draws a single column of an int in a box
//   needed because it takes 40mS to draw a whole int in a box
//     left: left edge of the box on the screen
//     top: top edge of the box
//     width: width of the box
//     height: height of the box
//     xOffset: left-hand offset to chars
//     yOffset: top offset to chars
//     x: position on the screen of the column to be drawn
//     i: integer value to be drawn
//     Font: Font
//     FG: foreground color
//     BG: background color
//-----------------------------------------------------------------------------
void DrawBoxIntCol(int left, int top, int width, int height, int xOffset, int yOffset,
    int x, int i, word Font, uint16_t FG, uint16_t BG) {

  if ((x >= left) && (x < left+width)) {
    DrawVLine(x, top, height, BG);

    if (FG == BG)
      return;

    ILI9341SetCursor(left+xOffset,top+yOffset);

    bool HasDigit = false;
    int n =  10000;
    while (n > 0) {
      if ((i >= n) || (n == 1) || HasDigit) {
        if (DrawCharCol('0' + (i / n), x, Font, FG))
          return;
        HasDigit = true;
      }
      i %= n;
      n /= 10;
    }
  }
}

//---------------------------------------------------------------------------
// showBPM
//---------------------------------------------------------------------------
void showBPM(int x) {
  const int left = 0;
  static int i;
  if (x == left)
    i = CurBPM;
  DrawBoxIntCol(left, 0, 30, 20, 4,16, x, i, LargeFont, TFT_WHITE, TFT_NAVY);
}

//---------------------------------------------------------------------------
// showQT
//---------------------------------------------------------------------------
#ifdef bHasQT
void showQT(int x) {
  const int left = TFT_WIDTH-30;
  static int i;
  if (x == left)
    i = CurQT;

  DrawBoxIntCol(left, 0, 30, 20, 2,16,
    x, i, LargeFont, TFT_WHITE, TFT_PURPLE);
}
#endif

//---------------------------------------------------------------------------
// showPAT
//---------------------------------------------------------------------------
#ifdef bHasPAT
void showPAT(int x) {
  #ifdef bHasQT
    const int y = 20;
  #else
    const int y = 0;
  #endif
  const int left = TFT_WIDTH-30;

  if ((CurPAT > 150) && (CurPAT < 500)) {
    static int i;
    if (x == left)
      i = CurPAT;

    DrawBoxIntCol(left, y, 30, 20, 2,16,
      x, i, LargeFont, TFT_BLACK, TFT_CYAN);
  } else {
    DrawBoxIntCol(left, y, 30, 20,
      2,17,
      x, 0, LargeFont, TFT_BLACK, TFT_BLACK);
  }
}
#endif
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
void loop(void)
{
  int ecg;
  int ppg = 0;

  static unsigned long nextTime = 0;
  unsigned long t;
  static int16_t prev_ppg = 0;

  t = millis();

  if (t > nextTime) {
    if (t > nextTime + 10)
      nextTime = t; else
      nextTime = nextTime + 5;

    #ifdef bFakeInput
      ecg = XanalogRead(ECG_IN);
    #else
      ecg = analogRead(ECG_IN);
    #endif

    if (SendingSerial)
      Serial.print(ecg);

    ecg = FilterNotch50HzQ1(ecg);
    //    ecg = FilterNotch50HzQ2(ecg);
    //    ecg = FilterLowPass(ecg);
    //    ecg = FilterNotch60Hz(ecg);

    #ifdef bHasPPG
      if ((mode == mdLargeECG) || (mode == mdSmallECG)) {
        #ifdef bFakeInput
          ppg = XanalogRead(PPG_IN);
        #else 
          ppg = analogRead(PPG_IN);
        #endif
        ppgmin = min(ppg, ppgmin);
      }
      ppgEnergy += abs(ppg - prev_ppg);
      prev_ppg = ppg;
      if (ppgEnergy > 10000)
        ppg = -1;
      if ((ppg < 1000) && (PPGreceived < PPGreceivedMin))
        PPGreceived++;
      if (SendingSerial) {
        Serial.print(' ');
        Serial.print(ppg);
      }
    #endif
    if (SendingSerial)
      Serial.println("");
    
    #ifdef bFakeECGoutput
      MakeFakePulse();
    #endif

    switch (mode) {
      case mdLargeECG: DrawTraceLarge(ecg / 4, ppg); break;
      case mdSmallECG: DrawTraceSmall(ecg / 4, ppg); break;
      case mdPoincare: AnalyseEPG(ecg / 4, 0, ppg); break;
      case mdBattery: DrawBattVolts(); break;
    }

    CheckButton();
    CheckLeadsOff();
    CheckBattery();

    if ((Serial.available()) && (Serial.read() == 'S'))
      SendingSerial = true;
  }
}

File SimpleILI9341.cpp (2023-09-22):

/***************************************************
  Arduino TFT graphics library for the ILI9341

  Derived from the TFT_ILI9341 library which was
  derived from the Adafruit_GFX library and the
  associated driver library.

 ****************************************************/

#include "SimpleILI9341.h"

#include <avr/pgmspace.h>
#include <SPI.h>

int16_t  Cursorx, Cursory, win_xe, win_ye;

uint16_t tft_width = 320;
uint16_t tft_height = 240;

uint8_t pen_width = 1; // if pen_width > 1 then draws with a disc of radius pen_width-1 // the overall width is pen_width*2-1

uint8_t letter_gap = 1;

uint16_t addr_row, addr_col;
uint8_t  mySPCR;

bool execDrawChar = true;
bool ILI9341fast = false;

uint8_t tft_CS   = 10; // Chip select control pin
uint8_t tft_DC   = 8;  // Data Command control pin
uint8_t tft_RST  = 7;  // Reset pin (could connect to Arduino RESET pin)

int touch_xmin = 340; 
int touch_ymin = 340; 
int touch_xmax = 3800;
int touch_ymax = 3800;
uint8_t touch_Rotation = 1;
uint8_t touch_CS = 2; // Chip select control pin

static inline void spiWait17(void) __attribute__((always_inline));
static inline void spiWait15(void) __attribute__((always_inline));
static inline void spiWait14(void) __attribute__((always_inline));
static inline void spiWait12(void) __attribute__((always_inline));
static inline void spiWrite16(uint16_t data, int16_t count) __attribute__((always_inline));

void tft_fastSetup(void);
void tft_fastPixel(uint16_t x, uint16_t y, uint16_t color);
void tft_setAddrWindow(int16_t x0, int16_t y0, int16_t x1, int16_t y1);

#define ILI9341_INIT_DELAY 0x80

// ILI9341 control registers
#define ILI9341_NOP     0x00
#define ILI9341_SWRESET 0x01
#define ILI9341_RDDID   0x04
#define ILI9341_RDDST   0x09
#define ILI9341_RDIMGFMT  0x0A
#define ILI9341_RDMADCTL  0x0B
#define ILI9341_RDPIXFMT  0x0C
#define ILI9341_RD_DISP_IMG_FMT 0x0D
#define ILI9341_RD_DISP_SIG_MODE 0x0E
#define ILI9341_RDSELFDIAG  0x0F
#define ILI9341_SLPIN   0x10
#define ILI9341_SLPOUT  0x11
#define ILI9341_PTLON   0x12
#define ILI9341_NORON   0x13
#define ILI9341_INVOFF  0x20
#define ILI9341_INVON   0x21
#define ILI9341_GAMMASET 0x26
#define ILI9341_DISPOFF 0x28
#define ILI9341_DISPON  0x29
#define ILI9341_CASET   0x2A
#define ILI9341_PASET   0x2B
#define ILI9341_RAMWR   0x2C
#define ILI9341_COLOR_SET 0x2D
#define ILI9341_RAMRD   0x2E
#define ILI9341_PTLAR   0x30
#define ILI9341_VSCRDEF 0x33
#define ILI9341_TEAR_EFF_OFF 0x34
#define ILI9341_TEAR_EFF_ON 0x35
#define ILI9341_MADCTL  0x36
#define ILI9341_VSCRSADD 0x37
#define ILI9341_IDLE_MODE_OFF 0x38
#define ILI9341_IDLE_MODE_ON 0x39
#define ILI9341_PIXFMT  0x3A
#define ILI9341_WRT_MEM_CTRL 0x3C
#define ILI9341_RD_MEM_CTRL 0x3E
#define ILI9341_SET_TEAR_SCANLINE 0x44
#define ILI9341_GET_SCANLINE 0x45
#define ILI9341_WRT_DISP_BRIGHT 0x51
#define ILI9341_RD_DISP_BRIGHT 0x52
#define ILI9341_WRT_CTRL_DISP 0x53
#define ILI9341_RD_CTRL_DISP 0x54
#define ILI9341_WRT_ADAPT_BRIGHT_CTRL 0x55
#define ILI9341_RD_ADAPT_BRIGHT_CTRL 0x56
#define ILI9341_WRT_CABC_MIN_BRIGHT 0x5E
#define ILI9341_RD_CABC_MIN_BRIGHT 0x5F
#define ILI9341_RGB_INTF_SIG_CTRL 0xB0
#define ILI9341_FRMCTR1 0xB1
#define ILI9341_FRMCTR2 0xB2
#define ILI9341_FRMCTR3 0xB3
#define ILI9341_INVCTR  0xB4
#define ILI9341_BLANKING_PORCH_CTRL 0xB5
#define ILI9341_DFUNCTR 0xB6
#define ILI9341_ENTRY_MODE_SET 0xB7
#define ILI9341_BKLGT_CTRL_1 0xB8
#define ILI9341_BKLGT_CTRL_2 0xB9
#define ILI9341_BKLGT_CTRL_3 0xBA
#define ILI9341_BKLGT_CTRL_4 0xBB
#define ILI9341_BKLGT_CTRL_5 0xBC
#define ILI9341_BKLGT_CTRL_7 0xBE
#define ILI9341_BKLGT_CTRL_8 0xBF
#define ILI9341_PWCTR1  0xC0
#define ILI9341_PWCTR2  0xC1
#define ILI9341_PWCTR3  0xC2
#define ILI9341_PWCTR4  0xC3
#define ILI9341_PWCTR5  0xC4
#define ILI9341_VMCTR1  0xC5
#define ILI9341_VMCTR2  0xC7
#define ILI9341_NV_MEM_WRT 0xD0
#define ILI9341_NV_MEM_PROT_KEY 0xD1
#define ILI9341_NV_MEM_STAT_RD 0xD2
#define ILI9341_RD_ID4 0xD3
#define ILI9341_RDID1   0xDA
#define ILI9341_RDID2   0xDB
#define ILI9341_RDID3   0xDC
#define ILI9341_RDID4   0xDD
#define ILI9341_GMCTRP1 0xE0
#define ILI9341_GMCTRN1 0xE1
#define ILI9341_GAMMA_CTRL_1 0xE2
#define ILI9341_GAMMA_CTRL_2 0xE3
#define ILI9341_INTF_CTRL 0xF6

/***************************************************************************************
** Function name:           tft_spiwrite
** Description:             Write 8 bits to SPI port
***************************************************************************************/
static void tft_spiwrite(uint8_t c)
{
  if (ILI9341fast) {
    uint8_t backupSPCR = SPCR;
    SPCR = mySPCR;
    SPDR = c;
    asm volatile( "nop\n\t" ::); // Sync SPIF and some commands need this delay otherwise they get lost!
    while (!(SPSR & _BV(SPIF)));
    SPCR = backupSPCR;
  } else
    SPI.transfer(c);
}

/***************************************************************************************
** Function name:           tft_writecommand
** Description:             Send an 8 bit command to the TFT
***************************************************************************************/
static void tft_writecommand(uint8_t c)
{
  digitalWrite(tft_DC, LOW);
  digitalWrite(tft_CS, LOW);
  tft_spiwrite(c);
  digitalWrite(tft_CS, HIGH);
}

/***************************************************************************************
** Function name:           tft_writedata
** Description:             Send a 8 bit data value to the TFT
***************************************************************************************/
static void tft_writedata(uint8_t c)
{
  digitalWrite(tft_DC, HIGH);
  digitalWrite(tft_CS, LOW);
  tft_spiwrite(c);
  digitalWrite(tft_CS, HIGH);
}

/***************************************************************************************
** Function name:           spi_begin
** Description:             Prepare for SPI communication to TFT
***************************************************************************************/
// If the SPI library has transaction support, these functions
// establish settings and protect from interference from other
// libraries.  Otherwise, they simply do nothing.

#ifdef SPI_HAS_TRANSACTION
  #ifdef SUPPORT_TRANSACTIONS

static inline void spi_begin(void) __attribute__((always_inline));

static inline void spi_begin(void) {
  SPI.beginTransaction(SPISettings(8000000, MSBFIRST, SPI_MODE0));
}

static inline void spi_end(void) __attribute__((always_inline));

static inline void spi_end(void) {
  while (!(SPSR & _BV(SPIF))); // wait for everything SPI to finish before freeing up the bus
  SPI.endTransaction();
}
  #else // we do not want to SUPPORT_TRANSACTIONS

#define spi_begin()
#define spi_end()

  #endif // SUPPORT_TRANSACTIONS

#else
#define spi_begin()
#define spi_end()
#endif
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
